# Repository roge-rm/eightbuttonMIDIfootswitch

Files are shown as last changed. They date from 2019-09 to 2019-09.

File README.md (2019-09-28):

# eightbuttonMIDIfootswitch
An eight button USB/5 pin MIDI footswitch. 

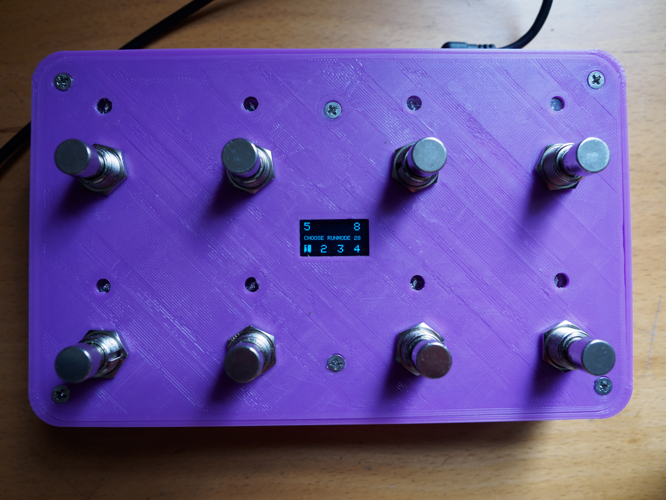
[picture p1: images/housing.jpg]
<br>
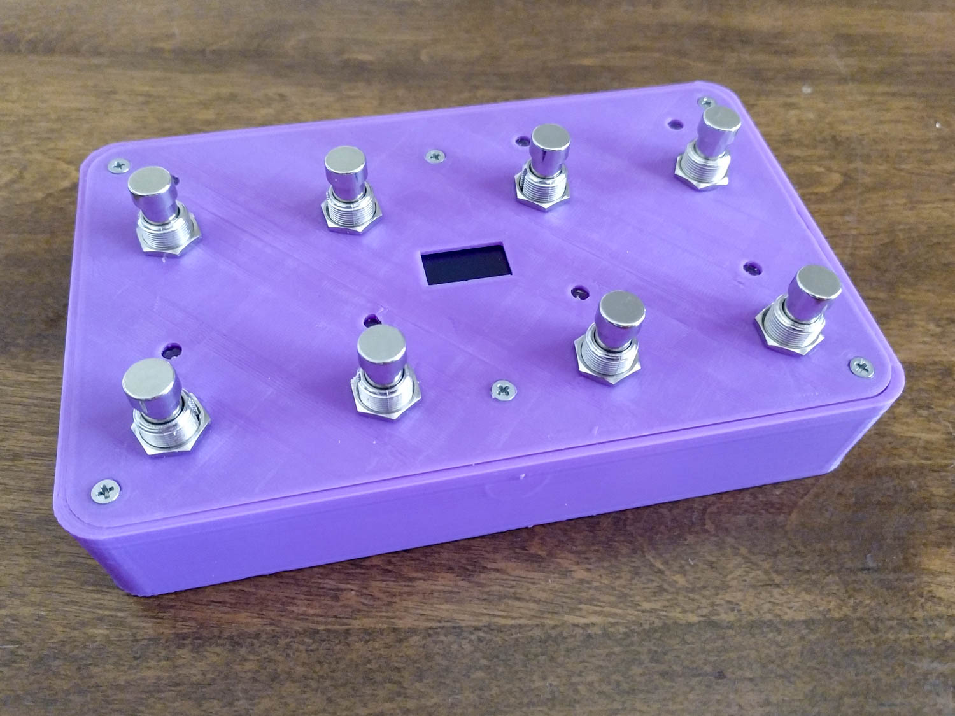
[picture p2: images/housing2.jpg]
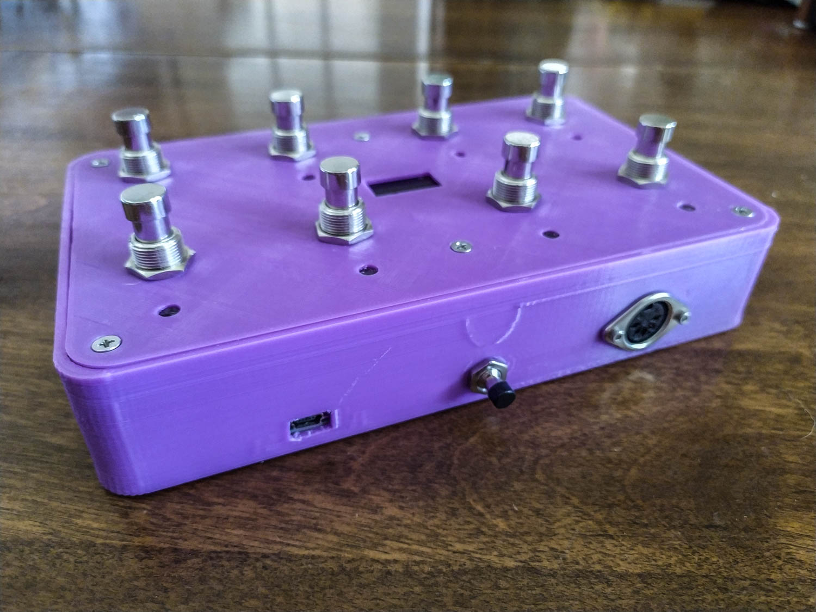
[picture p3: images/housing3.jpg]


Check it out on Thingiverse here: https://www.thingiverse.com/thing:3840065  
I've uploaded a video briefly showing how this works: https://www.youtube.com/watch?v=9XS2CDV4Rg0

I built this to go along with my [Synthstrom Deluge](https://synthstrom.com/product/deluge/) as a way to manage the new looping functionality in the (now out) 3.0 firmware. I wanted to be able to turn the loop mode on/off, as well as other various functions, either via USB MIDI or via standard 5-pin MIDI. This does that, and more! 

You can use either [toggle (latching)](https://github.com/hunked/eightbuttonMIDIfootswitch/blob/master/8buttonfootswitch-toggle.ino) or [momentary](https://github.com/hunked/eightbuttonMIDIfootswitch/blob/master/8buttonfootswitch-momentary.ino) switches. There are two versions of the code depending on which switch you use.

Currently there are 6 modes of operation selectable at boot. 
The selection screen can be returned to at any time by resetting the unit or pressing buttons 4 + 8 (top and bottom on the right side) together simultaneously.
- MIDI Note Momentary/Timed (on note sent on button press, off note sent after button is released (or preset time if using toggle switches))
- MIDI Note Toggle (press button once to turn on, press again to turn off)
- MIDI CC Momentary/Timed (same as mode 1 but with CC messages) 
- MIDI CC Toggle (same as mode 2 but with CC)
- Program Change (pressing each of the 8 buttons sends a different Program Change message)
- Settings Menu (change channels, MIDI messages, default options)

If you do not choose an option the footswitch will start the default (mode 1) after a set timeout (6 seconds). 

You can customize all of the messages sent by the footswitch. Currently the following options are configurable from the settings menu:
- CHAN - channel for NOTE/CC/PC messages (set separately)
- NOTE - MIDI note numbers and velocities
- CC - Control Change numbers and on/off values
- PC - Program Change numbers
- DEF - default runmode (RUNM), menu timeout (MENU), how long before OFF note/CC is sent (NOFF/COFF) (only in toggle version)
- LOAD - load values from EEPROM
- SAVE - save values to EEPROM (changes you make to settings will not be stored unless you press this)

The menu should be straight forward to use. There are a couple of screens that have no back button (due to all eight buttons being used for something else), they will time out to the previous screen after a set limit (which can be edited in the DEFaults menu).

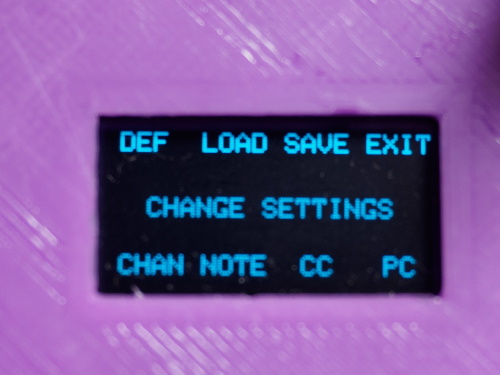
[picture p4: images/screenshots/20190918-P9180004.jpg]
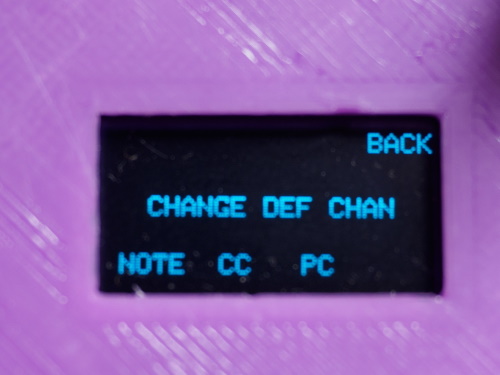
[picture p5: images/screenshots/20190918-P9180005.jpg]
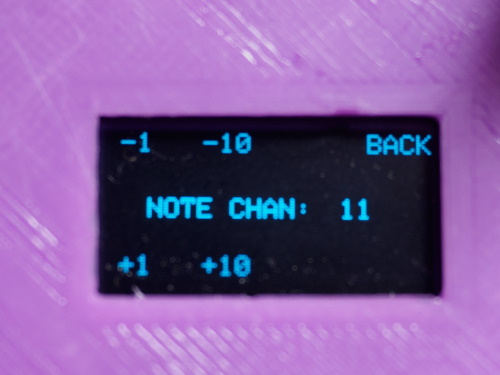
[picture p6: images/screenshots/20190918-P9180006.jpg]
<br>
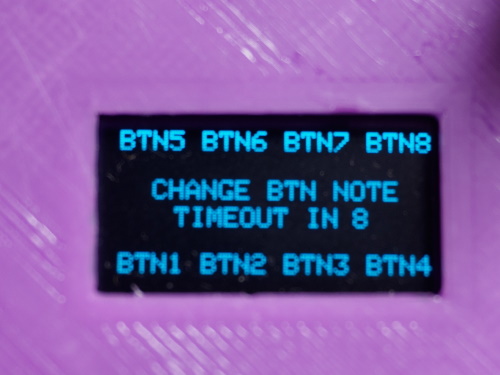
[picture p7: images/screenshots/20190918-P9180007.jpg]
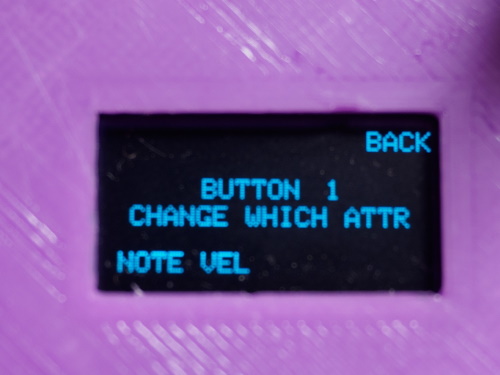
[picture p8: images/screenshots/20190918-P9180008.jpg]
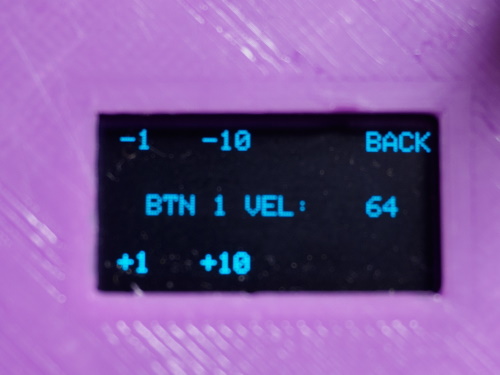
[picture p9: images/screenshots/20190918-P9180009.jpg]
<br>
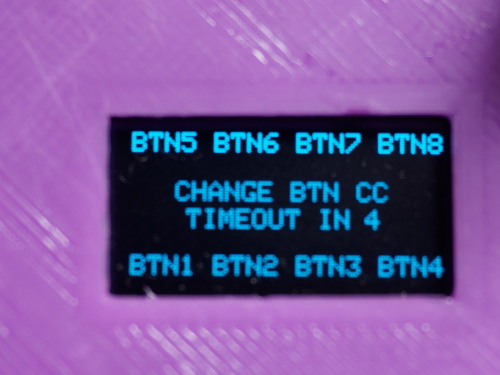
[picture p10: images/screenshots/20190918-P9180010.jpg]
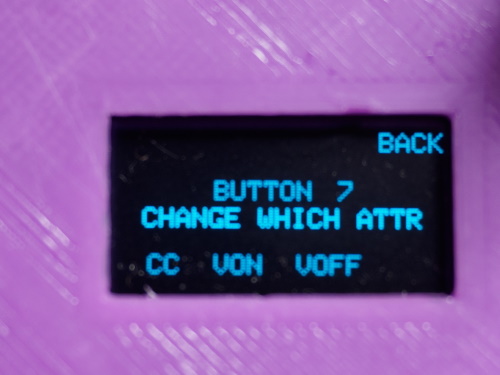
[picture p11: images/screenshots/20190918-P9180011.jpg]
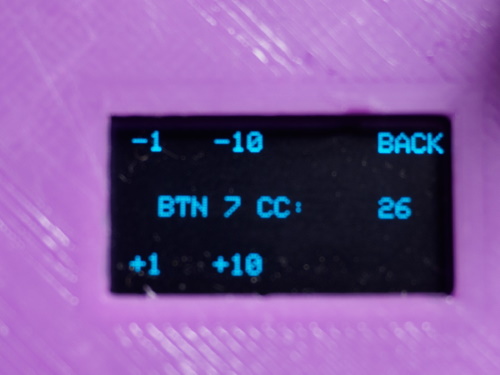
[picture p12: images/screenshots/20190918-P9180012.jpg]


#### Items used in this build:
- 3D Printer
- Soldering iron + solder
- Hookup wire (I used 28AWG) + appropriate heatshrink
- Tape (for binding wires, holding the OLED screen in place)
- Screwdriver
- Teensy ++2.0 (https://www.pjrc.com/store/teensypp.html)
- 8 x Guitar Footswitch, either momentary (https://www.aliexpress.com/item/32800932179.html) or latching (https://www.aliexpress.com/item/32826054526.html)
- 0.96" OLED I2C display (https://www.aliexpress.com/item/32896971385.html)
- 8 x 5mm 5V LEDs (https://www.aliexpress.com/item/32240559912.html)
- 5 pin MIDI port (https://www.aliexpress.com/item/32972269819.html)
- 2 x 220 ohm resistors for the MIDI port (see https://www.pjrc.com/teensy/td_libs_MIDI.html for wiring info)
- 7mm momentary push button (https://www.aliexpress.com/item/32790920961.html) as an easy way to update the Teensy without opening the case. Eventually I will replace this with a DC input jack.
- 6 x M3 countersunk screws, anything between 5 and 10mm in length will probably work (this is to hold the top of the housing down)
- 2 x M2 or M2.5 bolts and nuts, around 10mm length (to hold the MIDI port in place)

#### Rough pinout/wiring diagram:
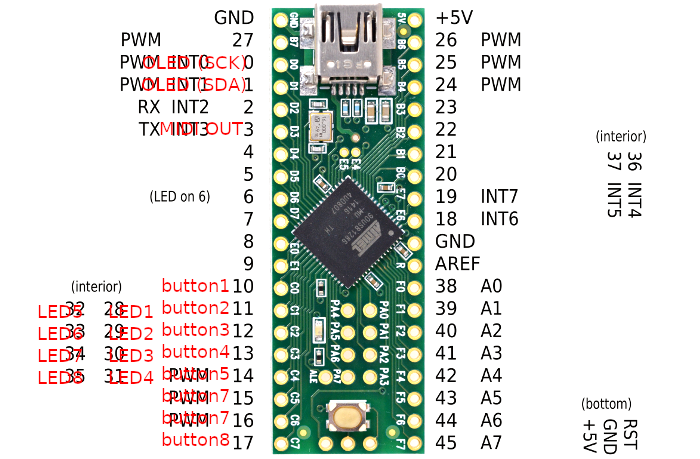
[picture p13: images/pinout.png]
Teensy ++2.0 Pinout


I have exported a schematic from KiCad that goes into more detail:
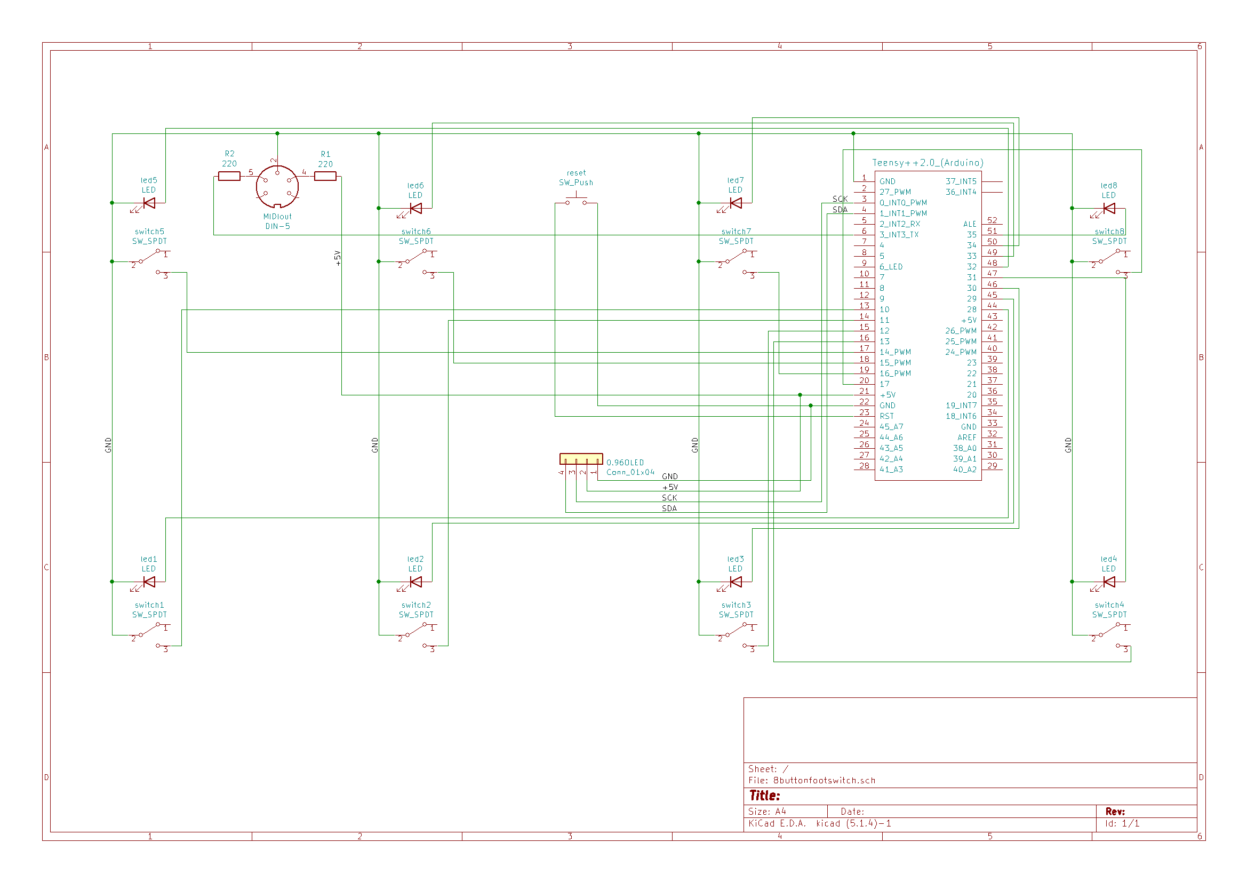
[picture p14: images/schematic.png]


#### Assembly instructions:
You can check out some pictures of my wiring [here](https://raw.githubusercontent.com/hunked/eightbuttonMIDIfootswitch/master/images/wiring1.jpg), [here](https://raw.githubusercontent.com/hunked/eightbuttonMIDIfootswitch/master/images/wiring2.jpg), and [here](https://raw.githubusercontent.com/hunked/eightbuttonMIDIfootswitch/master/images/wiring3.jpg).

- Print the top and bottom of the housing with your handy 3D printer (I use a Tevo Tarantula myself). I printed in PLA with a layer height of 0.3mm. You will need to use supports for the bottom of the housing.
- Install the OLED screen in the top housing. I initially planned to screw it into place but ended up using double sided tape for now. Screws would be a better idea but I haven't gone digging in my parts bin for something small enough yet.
- Wire the OLED screen to the Teensy, 5V and GND from wherever works for you and pin 0 for SCK/pin 1 for SDA.
- Install the footswitches in the top housing. Marvel at how footswitches are really hard to press with your fingers.
- Wire the footswitches to the Teensy. I wired the grounds first by daisy-chaining each switch to the next (and then the last switch the GND on the Teensy) and then wired the other sides of the switches to pins 10 through 17.
- Install the LEDs in the top housing. I made the holes in the top plate just large enough to jam the LEDs in so they don't need any glue. Maybe a little glue around the base wouldn't hurt.
- Wire the LEDs to the Teensy. I used pins 28 through 35 for the positive sides and then grounded each LED to the nearest switch. This is probably bad practice in electrical design but gosh darn if it doesn't make for some easier wiring.
- Install the 7mm momentary switch in the appropriate hole in the bottom of the case (you figure it out). This is handy for updating the firmware on the Teensy and I may use it as a way to change between footswitch functions in the future.
- Wire the 7mm momentary switch to the RST and GND pins on the end of the Teensy furthest from the USB port (the bottom, in the pinout diagram). 
- Solder 220 ohm resistors to pins 5 and 4 on the DIN-5 MIDI plug and install it into the bottom of the housing. See the MIDI library page [here](https://www.pjrc.com/teensy/td_libs_MIDI.html) for more information/diagrams.
- Wire the MIDI plug as shown in the [schematic](https://raw.githubusercontent.com/hunked/eightbuttonMIDIfootswitch/master/images/schematic.png). Pin 2 goes to GND (I ran it to the reset switch as it was close by), pin 5 (via 220 ohm resistor) goes to pin 3 on the Teensy, and pin 4 on the DIN-5 MIDI plug (via 220 ohm resistor) goes to a 5V pin on the Teensy (I used the one by the RST pin).
- Flash the appropriate code based on whether you used [momentary](https://github.com/hunked/eightbuttonMIDIfootswitch/blob/master/8buttonfootswitch-momentary.ino) or [toggle/latching](https://github.com/hunked/eightbuttonMIDIfootswitch/blob/master/8buttonfootswitch-toggle.ino) switches. If you used different pins than I did you will need to change the assignments in the code accordingly. **Make sure you set the USB Type (under Tools->USB Type) to MIDI.**
- Test it out! The LEDs will flash as you push the buttons and the screen will display the MIDI message number being sent. 
- Squish the wires into place, close the housing and screw it together. You may need to bore out the screw holes a bit with a drill.
- Stomp those switches until your roommate/neighbour/family member complains about the noise.

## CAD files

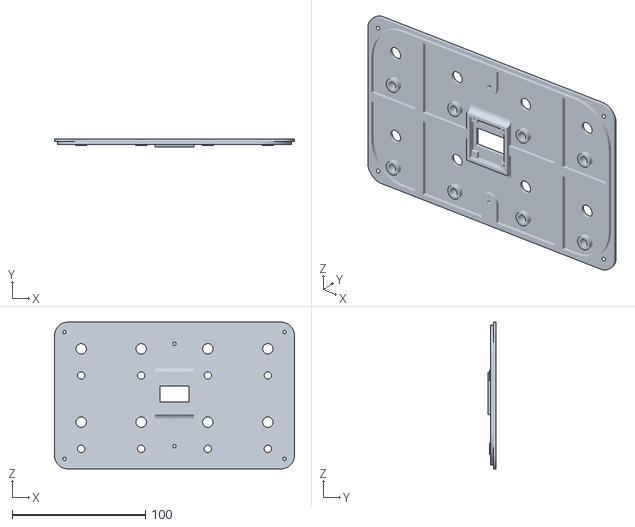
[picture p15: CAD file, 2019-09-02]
stl/8buttonMIDI-top-7mm.stl
180.0 x 6.00 x 110.0

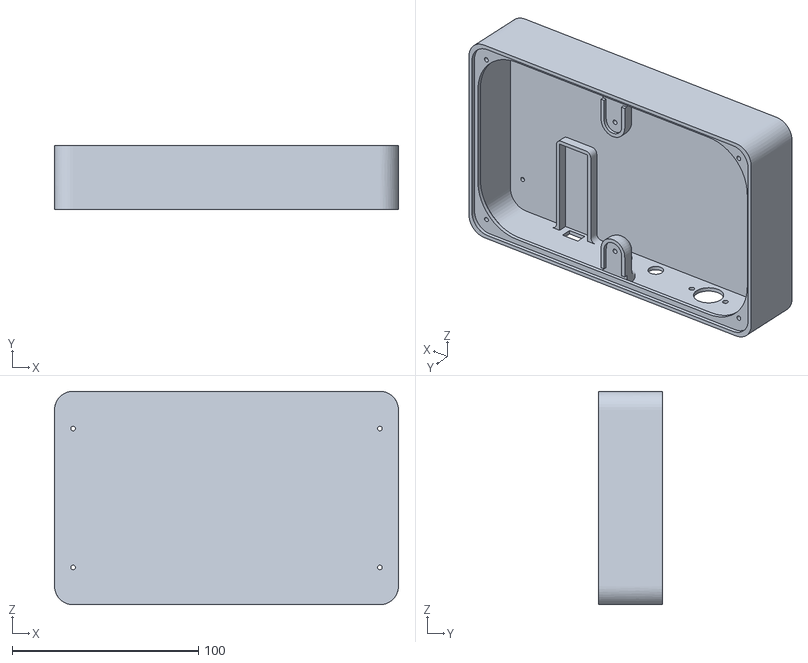
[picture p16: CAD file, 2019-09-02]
stl/8buttonMIDI-bottom-power&reset.stl
184.5 x 34.1 x 114.5

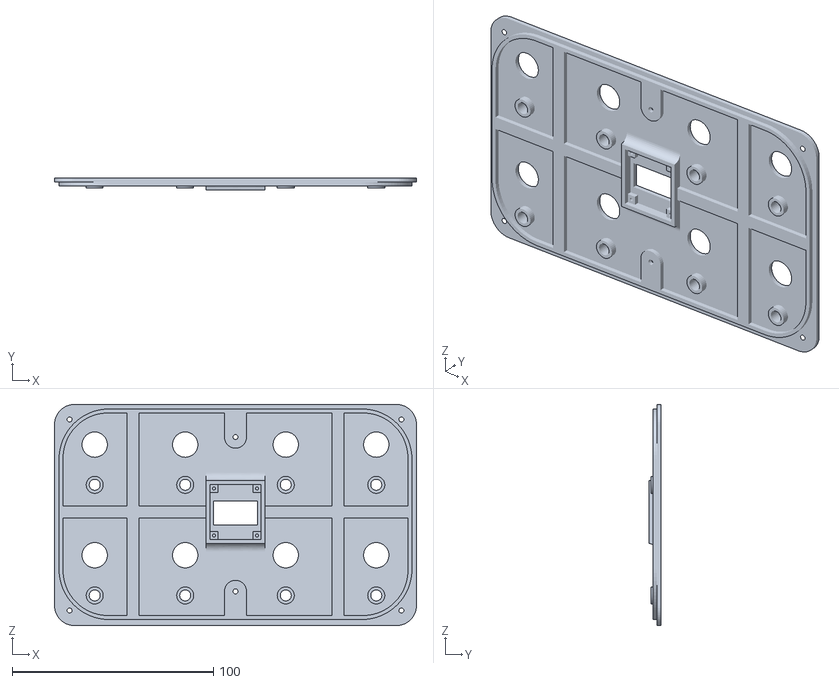
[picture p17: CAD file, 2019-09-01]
stl/8buttonMIDI-top.stl
180.0 x 6.00 x 110.0

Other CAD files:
stl/8buttonMIDI-bottom.stl

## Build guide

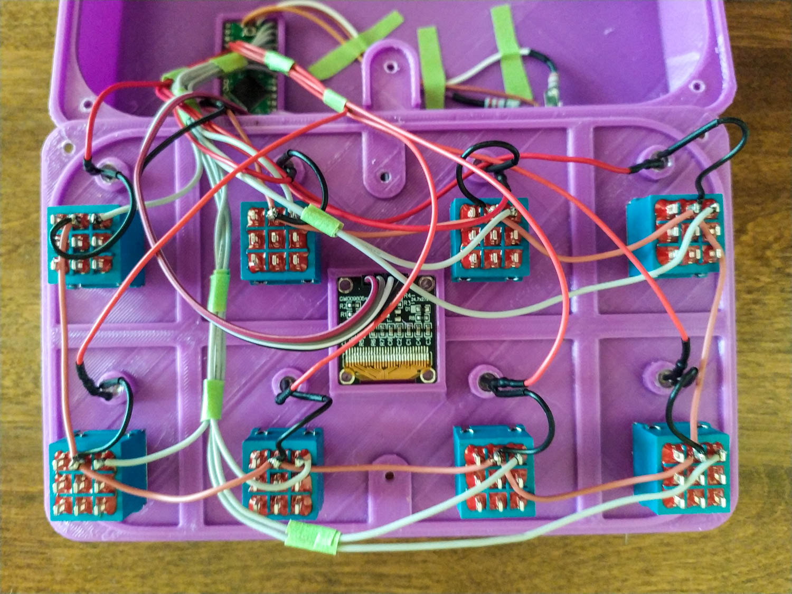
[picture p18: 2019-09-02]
images/wiring1.jpg

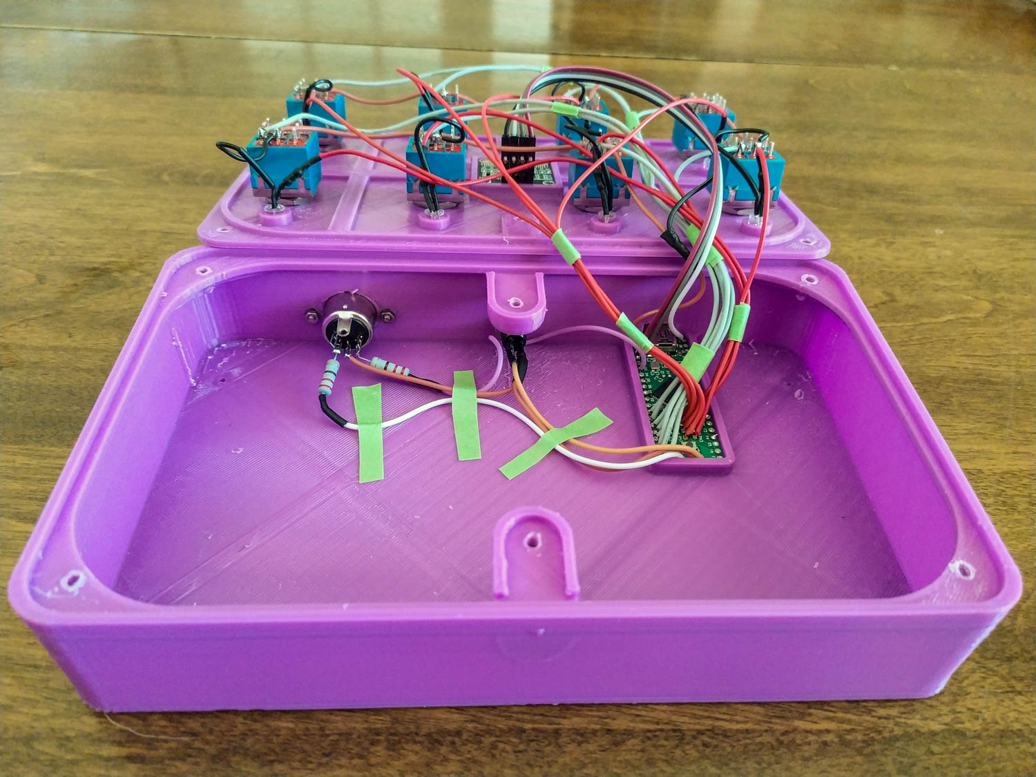
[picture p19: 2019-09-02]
images/wiring2.jpg

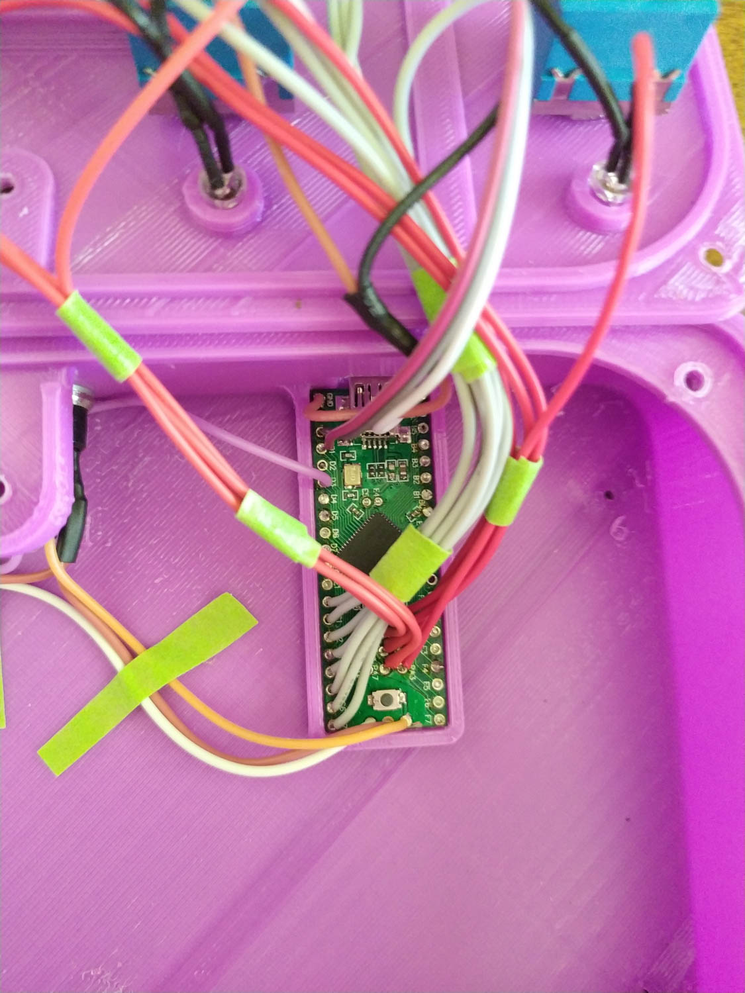
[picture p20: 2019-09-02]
images/wiring3.jpg

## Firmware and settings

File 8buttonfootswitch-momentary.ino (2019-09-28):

/*
 * This is for momentary switches. If you have toggle switches check out 8buttonfootswitch-toggle
 */

#include <SPI.h>
#include <Wire.h>
#include <Bounce.h>
#include <MIDI.h>
#include <EEPROM.h>
#include <Adafruit_GFX.h>
#include <Adafruit_SSD1306.h>

#define SCREEN_WIDTH 128 //OLED display width, in pixels
#define SCREEN_HEIGHT 64 //OLED display height, in pixels

//Declaration for an SSD1306 display connected to I2C (SDA, SCL pins)
#define OLED_RESET -1 //Reset pin # (or -1 if sharing Arduino reset pin)
Adafruit_SSD1306 display(SCREEN_WIDTH, SCREEN_HEIGHT, &Wire, OLED_RESET);

//Create MIDI instance for 5 pin MIDI output
MIDI_CREATE_INSTANCE(HardwareSerial, Serial1, MIDI);

//Declare pins for footswitches
const byte switchPin[8] = {10, 11, 12, 13, 14, 15, 16, 17};

//Declare pins for LEDs;
const byte ledPin[8] = {32, 33, 34, 35, 28, 29, 30, 31};
const int ledDelay = 500; //How long to light LEDs up for visual confirmation

//Default channel for MIDI notes, CC, program change, control change
int MIDI_NOTE_CHAN;
int MIDI_CC_CHAN;
int MIDI_PC_CHAN;

//Arrays are declared here but loaded from EEPROM/defaults in eepromREAD()
int switchNote[8];
int switchVel[8];
int switchCC[8];
int switchCCValOn[8];
int switchCCValOff[8];
int switchPC[8];

//Switch states for runmodes that require toggling
bool switchState[8] = {0, 0, 0, 0, 0, 0, 0, 0};

//Create Bounce objects for each button and switch.
//Default debounce time is 5ms
const int DEBOUNCE_TIME = 5;

Bounce button1 = Bounce(switchPin[0], DEBOUNCE_TIME);
Bounce button2 = Bounce(switchPin[1], DEBOUNCE_TIME);
Bounce button3 = Bounce(switchPin[2], DEBOUNCE_TIME);
Bounce button4 = Bounce(switchPin[3], DEBOUNCE_TIME);
Bounce button5 = Bounce(switchPin[4], DEBOUNCE_TIME);
Bounce button6 = Bounce(switchPin[5], DEBOUNCE_TIME);
Bounce button7 = Bounce(switchPin[6], DEBOUNCE_TIME);
Bounce button8 = Bounce(switchPin[7], DEBOUNCE_TIME);

//Track runmode (function of footswitch) as well as pick default option if no change is made before timeout. Default timeout is 6000ms.
//0 = Startup screen (runmode select)
//1 = MIDI Note ON+OFF (timed), 2 = MIDI Note Toggle (must hit switch again to turn off)
//3 = MIDI CC ON+OFF (timed), 4 = MIDI CC Toggle (same as MIDI Note, but with CC)
//5 = Program Change, 8 = Settings
int RUNMODE = 0;
int RUNMODE_DEFAULT; //set by EEPROM
unsigned int RUNMODE_TIMEOUT = 6000;
const int RUNMODE_LONGTIMEOUT = 31000;

//Counter setup for menus requiring timeouts (due to lack of a back button)
unsigned long previousMillis = 0;

//For settings menu navigation
int menuCat[3] = {0, 0, 0};
unsigned long MENU_TIMEOUT;
unsigned long currentMillis = 0;

void setup() {
  eepromREAD(); //Set variable values from EEPROM (or defaults if EEPROM has not been written)

  //Serial.begin(9600); //Debugging

  MIDI.begin();

  //Configure switch pins as for input mode with pullup resistors
  pinMode (switchPin[0], INPUT_PULLUP);
  pinMode (switchPin[1], INPUT_PULLUP);
  pinMode (switchPin[2], INPUT_PULLUP);
  pinMode (switchPin[3], INPUT_PULLUP);
  pinMode (switchPin[4], INPUT_PULLUP);
  pinMode (switchPin[5], INPUT_PULLUP);
  pinMode (switchPin[6], INPUT_PULLUP);
  pinMode (switchPin[7], INPUT_PULLUP);

  //Configure LED pins for output
  pinMode (ledPin[0], OUTPUT);
  pinMode (ledPin[1], OUTPUT);
  pinMode (ledPin[2], OUTPUT);
  pinMode (ledPin[3], OUTPUT);
  pinMode (ledPin[4], OUTPUT);
  pinMode (ledPin[5], OUTPUT);
  pinMode (ledPin[6], OUTPUT);
  pinMode (ledPin[7], OUTPUT);

  //SSD1306_SWITCHCAPVCC = generate display voltage from 3.3V internally
  if (!display.begin(SSD1306_SWITCHCAPVCC, 0x3C)) { //Address 0x3C for 128x64
    Serial.println(F("SSD1306 allocation failed"));
    for (;;); //Don't proceed, loop forever
  }

  updatebuttons(); //Pull initial button status to prevent phantom MIDI messages from being sent once the loop starts

  display.display();
  delay(500);

  display.clearDisplay();
}

void loop() {
  currentMillis = millis();
  display.clearDisplay();
  display.setTextSize(2);
  display.setTextColor(WHITE);

  updatebuttons(); //Poll for button presses

  if (RUNMODE == 0) {
    runmodeSELECTMODE();
  } else if (RUNMODE == 1) {
    runmodeMIDINOTETIMED();
  } else if (RUNMODE == 2) {
    runmodeMIDINOTETOGGLE();
  } else if (RUNMODE == 3) {
    runmodeCCTIMED();
  } else if (RUNMODE == 4) {
    runmodeCCTOGGLE();
  } else if (RUNMODE == 5) {
    runmodePROGRAMCHANGE();
  } else if (RUNMODE == 8) {
    runmodeSETTINGS();
  }

  //Break back to mode select. Set timeout to 31 seconds to give user more time for a selection
  if (button4.risingEdge() && button8.risingEdge()) {
    RUNMODE = 0;
    RUNMODE_TIMEOUT = RUNMODE_LONGTIMEOUT;
    resetSWITCHES();
    resetMENU();
    previousMillis = currentMillis;
  }

  while (usbMIDI.read()) //Ignore incoming MIDI
  {
  }
}

void updatebuttons() {
  button1.update();
  button2.update();
  button3.update();
  button4.update();
  button5.update();
  button6.update();
  button7.update();
  button8.update();
}

void runmodeSELECTMODE() { //Give choice between running modes, choose default mode after timeout if no option selected
  //unsigned long currentMillis = millis();
  long timeOut = (RUNMODE_TIMEOUT / 1000 - ((currentMillis - previousMillis) / 1000));

  display.setTextColor(WHITE, BLACK);
  display.setTextSize(1);
  display.setCursor(10, 34);
  display.println(F("CHOOSE RUNMODE"));
  display.setCursor(100, 34);
  display.println(timeOut);

  display.setTextSize(2);
  display.setCursor(10, 50);
  if (RUNMODE_DEFAULT == 1) {
    display.setTextColor(BLACK, WHITE);
  } else display.setTextColor(WHITE, BLACK);
  display.println(F("1"));
  display.setCursor(40, 50);
  if (RUNMODE_DEFAULT == 2) {
    display.setTextColor(BLACK, WHITE);
  } else display.setTextColor(WHITE, BLACK);
  display.println(F("2"));
  display.setCursor(70, 50);
  if (RUNMODE_DEFAULT == 3) {
    display.setTextColor(BLACK, WHITE);
  } else display.setTextColor(WHITE, BLACK);
  display.println(F("3"));
  display.setCursor(100, 50);
  if (RUNMODE_DEFAULT == 4) {
    display.setTextColor(BLACK, WHITE);
  } else display.setTextColor(WHITE, BLACK);
  display.println(F("4"));
  display.setCursor(10, 10);
  if (RUNMODE_DEFAULT == 5) {
    display.setTextColor(BLACK, WHITE);
  } else display.setTextColor(WHITE, BLACK);
  display.println(F("5"));
  display.setCursor(100, 10);
  display.setTextColor(WHITE, BLACK);
  display.println(F("8"));

  if (button1.fallingEdge()) {
    RUNMODE = 1;
    blinkLED(1);
    previousMillis = currentMillis;
  }
  if (button2.fallingEdge()) {
    RUNMODE = 2;
    blinkLED(2);
    previousMillis = currentMillis;
  }
  if (button3.fallingEdge()) {
    RUNMODE = 3;
    blinkLED(3);
    previousMillis = currentMillis;
  }
  if (button4.fallingEdge()) {
    RUNMODE = 4;
    blinkLED(4);
    previousMillis = currentMillis;
  }
  if (button5.fallingEdge()) {
    RUNMODE = 5;
    blinkLED(5);
    previousMillis = currentMillis;
  }
  if (button8.fallingEdge()) {
    RUNMODE = 8;
    blinkLED(8);
    previousMillis = currentMillis;
  }

  if (currentMillis - previousMillis >= RUNMODE_TIMEOUT) {
    RUNMODE = RUNMODE_DEFAULT;
    blinkLED(RUNMODE_DEFAULT);
    previousMillis = currentMillis;
  }

  display.setTextColor(WHITE, BLACK);
  display.display();
}


void runmodeMIDINOTETIMED() {
  if (button1.fallingEdge()) {
    display.setCursor(10, 50);
    display.println(switchNote[0]);
    digitalWrite(ledPin[0], HIGH);
    usbMIDI.sendNoteOn(switchNote[0], switchVel[0], MIDI_NOTE_CHAN);
    MIDI.sendNoteOn(switchNote[0], switchVel[0], MIDI_NOTE_CHAN);
  }
  else if (button1.risingEdge()) {
    display.setCursor(10, 50);
    display.println(switchNote[0]);
    usbMIDI.sendNoteOff(switchNote[0], 0, MIDI_NOTE_CHAN);
    MIDI.sendNoteOff(switchNote[0], 0, MIDI_NOTE_CHAN);
    digitalWrite(ledPin[0], LOW);
  }

  if (button2.fallingEdge()) {
    display.setCursor(40, 50);
    display.println(switchNote[1]);
    digitalWrite(ledPin[1], HIGH);
    usbMIDI.sendNoteOn(switchNote[1], switchVel[1], MIDI_NOTE_CHAN);
    MIDI.sendNoteOn(switchNote[1], switchVel[1], MIDI_NOTE_CHAN);
  }
  else if (button2.risingEdge()) {
    display.setCursor(40, 50);
    display.println(switchNote[1]);
    usbMIDI.sendNoteOff(switchNote[1], 0, MIDI_NOTE_CHAN);
    MIDI.sendNoteOff(switchNote[1], 0, MIDI_NOTE_CHAN);
    digitalWrite(ledPin[1], LOW);
  }

  if (button3.fallingEdge()) {
    display.setCursor(70, 50);
    display.println(switchNote[2]);
    digitalWrite(ledPin[2], HIGH);
    usbMIDI.sendNoteOn(switchNote[2], switchVel[2], MIDI_NOTE_CHAN);
    MIDI.sendNoteOn(switchNote[2], switchVel[2], MIDI_NOTE_CHAN);
  }
  else if (button3.risingEdge()) {
    display.setCursor(70, 50);
    display.println(switchNote[2]);
    usbMIDI.sendNoteOff(switchNote[2], 0, MIDI_NOTE_CHAN);
    MIDI.sendNoteOff(switchNote[2], 0, MIDI_NOTE_CHAN);
    digitalWrite(ledPin[2], LOW);
  }

  if (button4.fallingEdge()) {
    display.setCursor(100, 50);
    display.println(switchNote[3]);
    digitalWrite(ledPin[3], HIGH);
    usbMIDI.sendNoteOn(switchNote[3], switchVel[3], MIDI_NOTE_CHAN);
    MIDI.sendNoteOn(switchNote[3], switchVel[3], MIDI_NOTE_CHAN);
  }
  else if (button4.risingEdge()) {
    display.setCursor(100, 50);
    display.println(switchNote[3]);
    usbMIDI.sendNoteOff(switchNote[3], 0, MIDI_NOTE_CHAN);
    MIDI.sendNoteOff(switchNote[3], 0, MIDI_NOTE_CHAN);
    digitalWrite(ledPin[3], LOW);
  }

  if (button5.fallingEdge()) {
    display.setCursor(10, 10);
    display.println(switchNote[4]);
    digitalWrite(ledPin[4], HIGH);
    usbMIDI.sendNoteOn(switchNote[4], switchVel[4], MIDI_NOTE_CHAN);
    MIDI.sendNoteOn(switchNote[4], switchVel[4], MIDI_NOTE_CHAN);
  }
  else if (button5.risingEdge()) {
    display.setCursor(10, 10);
    display.println(switchNote[4]);
    usbMIDI.sendNoteOff(switchNote[4], 0, MIDI_NOTE_CHAN);
    MIDI.sendNoteOff(switchNote[4], 0, MIDI_NOTE_CHAN);
    digitalWrite(ledPin[4], LOW);
  }

  if (button6.fallingEdge()) {
    display.setCursor(40, 10);
    display.println(switchNote[5]);
    digitalWrite(ledPin[5], HIGH);
    usbMIDI.sendNoteOn(switchNote[5], switchVel[5], MIDI_NOTE_CHAN);
    MIDI.sendNoteOn(switchNote[5], switchVel[5], MIDI_NOTE_CHAN);
  }
  else if (button6.risingEdge()) {
    display.setCursor(40, 10);
    display.println(switchNote[5]);
    usbMIDI.sendNoteOff(switchNote[5], 0, MIDI_NOTE_CHAN);
    MIDI.sendNoteOff(switchNote[5], 0, MIDI_NOTE_CHAN);
    digitalWrite(ledPin[5], LOW);
  }

  if (button7.fallingEdge()) {
    display.setCursor(70, 10);
    display.println(switchNote[6]);
    digitalWrite(ledPin[6], HIGH);
    usbMIDI.sendNoteOn(switchNote[6], switchVel[6], MIDI_NOTE_CHAN);
    MIDI.sendNoteOn(switchNote[6], switchVel[6], MIDI_NOTE_CHAN);
  }
  else if (button7.risingEdge()) {
    display.setCursor(70, 10);
    display.println(switchNote[6]);
    usbMIDI.sendNoteOff(switchNote[6], 0, MIDI_NOTE_CHAN);
    MIDI.sendNoteOff(switchNote[6], 0, MIDI_NOTE_CHAN);
    digitalWrite(ledPin[6], LOW);
  }

  if (button8.fallingEdge()) {
    display.setCursor(100, 10);
    display.println(switchNote[7]);
    digitalWrite(ledPin[7], HIGH);
    usbMIDI.sendNoteOn(switchNote[7], switchVel[7], MIDI_NOTE_CHAN);
    MIDI.sendNoteOn(switchNote[7], switchVel[7], MIDI_NOTE_CHAN);
  }
  else if (button8.risingEdge()) {
    display.setCursor(100, 10);
    display.println(switchNote[7]);
    usbMIDI.sendNoteOff(switchNote[7], 0, MIDI_NOTE_CHAN);
    MIDI.sendNoteOff(switchNote[7], 0, MIDI_NOTE_CHAN);
    digitalWrite(ledPin[7], LOW);
  }

  display.display();
}

void runmodeMIDINOTETOGGLE() {
  if (button1.fallingEdge()) {
    display.setCursor(10, 50);
    display.println(switchNote[0]);
    if (!switchState[0]) {
      digitalWrite(ledPin[0], HIGH);
      usbMIDI.sendNoteOn(switchNote[0], switchVel[0], MIDI_NOTE_CHAN);
      MIDI.sendNoteOn(switchNote[0], switchVel[0], MIDI_NOTE_CHAN);
      switchState[0] = 1;
    } else {
      usbMIDI.sendNoteOff(switchNote[0], 0, MIDI_NOTE_CHAN);
      MIDI.sendNoteOff(switchNote[0], 0, MIDI_NOTE_CHAN);
      digitalWrite(ledPin[0], LOW);
      switchState[0] = 0;
    }
  }

  if (button2.fallingEdge()) {
    display.setCursor(40, 50);
    display.println(switchNote[1]);
    if (!switchState[1]) {
      digitalWrite(ledPin[1], HIGH);
      usbMIDI.sendNoteOn(switchNote[1], switchVel[1], MIDI_NOTE_CHAN);
      MIDI.sendNoteOn(switchNote[1], switchVel[1], MIDI_NOTE_CHAN);
      switchState[1] = 1;
    } else {
      usbMIDI.sendNoteOff(switchNote[1], 0, MIDI_NOTE_CHAN);
      MIDI.sendNoteOff(switchNote[1], 0, MIDI_NOTE_CHAN);
      digitalWrite(ledPin[1], LOW);
      switchState[1] = 0;
    }
  }

  if (button3.fallingEdge()) {
    display.setCursor(70, 50);
    display.println(switchNote[2]);
    if (!switchState[2]) {
      digitalWrite(ledPin[2], HIGH);
      usbMIDI.sendNoteOn(switchNote[2], switchVel[2], MIDI_NOTE_CHAN);
      MIDI.sendNoteOn(switchNote[2], switchVel[2], MIDI_NOTE_CHAN);
      switchState[2] = 1;
    } else {
      usbMIDI.sendNoteOff(switchNote[2], 0, MIDI_NOTE_CHAN);
      MIDI.sendNoteOff(switchNote[2], 0, MIDI_NOTE_CHAN);
      digitalWrite(ledPin[2], LOW);
      switchState[2] = 0;
    }
  }

  if (button4.fallingEdge()) {
    display.setCursor(100, 50);
    display.println(switchNote[3]);
    if (!switchState[3]) {
      digitalWrite(ledPin[3], HIGH);
      usbMIDI.sendNoteOn(switchNote[3], switchVel[3], MIDI_NOTE_CHAN);
      MIDI.sendNoteOn(switchNote[3], switchVel[3], MIDI_NOTE_CHAN);
      switchState[3] = 1;
    } else {
      usbMIDI.sendNoteOff(switchNote[3], 0, MIDI_NOTE_CHAN);
      MIDI.sendNoteOff(switchNote[3], 0, MIDI_NOTE_CHAN);
      digitalWrite(ledPin[3], LOW);
      switchState[3] = 0;
    }
  }

  if (button5.fallingEdge()) {
    display.setCursor(10, 10);
    display.println(switchNote[4]);
    if (!switchState[4]) {
      digitalWrite(ledPin[4], HIGH);
      usbMIDI.sendNoteOn(switchNote[4], switchVel[4], MIDI_NOTE_CHAN);
      MIDI.sendNoteOn(switchNote[4], switchVel[4], MIDI_NOTE_CHAN);
      switchState[4] = 1;
    } else {
      usbMIDI.sendNoteOff(switchNote[4], 0, MIDI_NOTE_CHAN);
      MIDI.sendNoteOff(switchNote[4], 0, MIDI_NOTE_CHAN);
      digitalWrite(ledPin[4], LOW);
      switchState[4] = 0;
    }
  }

  if (button6.fallingEdge()) {
    display.setCursor(40, 10);
    display.println(switchNote[5]);
    if (!switchState[5]) {
      digitalWrite(ledPin[5], HIGH);
      usbMIDI.sendNoteOn(switchNote[5], switchVel[5], MIDI_NOTE_CHAN);
      MIDI.sendNoteOn(switchNote[5], switchVel[5], MIDI_NOTE_CHAN);
      switchState[5] = 1;
    } else {
      usbMIDI.sendNoteOff(switchNote[5], 0, MIDI_NOTE_CHAN);
      MIDI.sendNoteOff(switchNote[5], 0, MIDI_NOTE_CHAN);
      digitalWrite(ledPin[5], LOW);
      switchState[5] = 0;
    }
  }

  if (button7.fallingEdge()) {
    display.setCursor(70, 10);
    display.println(switchNote[6]);
    if (!switchState[6]) {
      digitalWrite(ledPin[6], HIGH);
      usbMIDI.sendNoteOn(switchNote[6], switchVel[6], MIDI_NOTE_CHAN);
      MIDI.sendNoteOn(switchNote[6], switchVel[6], MIDI_NOTE_CHAN);
      switchState[6] = 1;
    } else {
      usbMIDI.sendNoteOff(switchNote[6], 0, MIDI_NOTE_CHAN);
      MIDI.sendNoteOff(switchNote[6], 0, MIDI_NOTE_CHAN);
      digitalWrite(ledPin[6], LOW);
      switchState[6] = 0;
    }
  }

  if (button8.fallingEdge()) {
    display.setCursor(100, 10);
    display.println(switchNote[7]);
    if (!switchState[7]) {
      digitalWrite(ledPin[7], HIGH);
      usbMIDI.sendNoteOn(switchNote[7], switchVel[7], MIDI_NOTE_CHAN);
      MIDI.sendNoteOn(switchNote[7], switchVel[7], MIDI_NOTE_CHAN);
      switchState[7] = 1;
    } else {
      usbMIDI.sendNoteOff(switchNote[7], 0, MIDI_NOTE_CHAN);
      MIDI.sendNoteOff(switchNote[7], 0, MIDI_NOTE_CHAN);
      digitalWrite(ledPin[7], LOW);
      switchState[7] = 0;
    }
  }

  display.display();
}

void runmodeCCTIMED() {
  if (button1.fallingEdge()) {
    display.setCursor(10, 50);
    display.println(switchCC[0]);
    digitalWrite(ledPin[0], HIGH);
    usbMIDI.sendControlChange(switchCC[0], switchCCValOn[0], MIDI_CC_CHAN);
    MIDI.sendControlChange(switchCC[0], switchCCValOn[0], MIDI_CC_CHAN);
  }
  else if (button1.risingEdge()) {
    display.setCursor(10, 50);
    display.println(switchCC[0]);
    usbMIDI.sendControlChange(switchCC[0], switchCCValOff[0], MIDI_CC_CHAN);
    MIDI.sendControlChange(switchCC[0], switchCCValOff[0], MIDI_CC_CHAN);
    digitalWrite(ledPin[0], LOW);
  }

  if (button2.fallingEdge()) {
    display.setCursor(40, 50);
    display.println(switchCC[1]);
    digitalWrite(ledPin[1], HIGH);
    usbMIDI.sendControlChange(switchCC[1], switchCCValOn[1], MIDI_CC_CHAN);
    MIDI.sendControlChange(switchCC[1], switchCCValOn[1], MIDI_CC_CHAN);
  }
  else if (button2.risingEdge()) {
    display.setCursor(40, 50);
    display.println(switchCC[1]);
    usbMIDI.sendControlChange(switchCC[1], switchCCValOff[1], MIDI_CC_CHAN);
    MIDI.sendControlChange(switchCC[1], switchCCValOff[1], MIDI_CC_CHAN);
    digitalWrite(ledPin[1], LOW);
  }

  if (button3.fallingEdge()) {
    display.setCursor(70, 50);
    display.println(switchCC[2]);
    digitalWrite(ledPin[2], HIGH);
    usbMIDI.sendControlChange(switchCC[2], switchCCValOn[2], MIDI_CC_CHAN);
    MIDI.sendControlChange(switchCC[2], switchCCValOn[2], MIDI_CC_CHAN);
  }
  else if (button3.risingEdge()) {
    display.setCursor(70, 50);
    display.println(switchCC[2]);
    usbMIDI.sendControlChange(switchCC[2], switchCCValOff[2], MIDI_CC_CHAN);
    MIDI.sendControlChange(switchCC[2], switchCCValOff[2], MIDI_CC_CHAN);
    digitalWrite(ledPin[2], LOW);
  }

  if (button4.fallingEdge()) {
    display.setCursor(100, 50);
    display.println(switchCC[3]);
    digitalWrite(ledPin[3], HIGH);
    usbMIDI.sendControlChange(switchCC[3], switchCCValOn[3], MIDI_CC_CHAN);
    MIDI.sendControlChange(switchCC[3], switchCCValOn[3], MIDI_CC_CHAN);
  }
  else if (button4.risingEdge()) {
    display.setCursor(100, 50);
    display.println(switchCC[3]);
    usbMIDI.sendControlChange(switchCC[3], switchCCValOff[3], MIDI_CC_CHAN);
    MIDI.sendControlChange(switchCC[3], switchCCValOff[3], MIDI_CC_CHAN);
    digitalWrite(ledPin[3], LOW);
  }

  if (button5.fallingEdge()) {
    display.setCursor(10, 10);
    display.println(switchCC[4]);
    digitalWrite(ledPin[4], HIGH);
    usbMIDI.sendControlChange(switchCC[4], switchCCValOn[4], MIDI_CC_CHAN);
    MIDI.sendControlChange(switchCC[4], switchCCValOn[4], MIDI_CC_CHAN);
  }
  else if (button5.risingEdge()) {
    display.setCursor(10, 10);
    display.println(switchCC[4]);
    usbMIDI.sendControlChange(switchCC[4], switchCCValOff[4], MIDI_CC_CHAN);
    MIDI.sendControlChange(switchCC[4], switchCCValOff[4], MIDI_CC_CHAN);
    digitalWrite(ledPin[4], LOW);
  }

  if (button6.fallingEdge()) {
    display.setCursor(40, 10);
    display.println(switchCC[5]);
    digitalWrite(ledPin[5], HIGH);
    usbMIDI.sendControlChange(switchCC[5], switchCCValOn[5], MIDI_CC_CHAN);
    MIDI.sendControlChange(switchCC[5], switchCCValOn[5], MIDI_CC_CHAN);
  }
  else if (button6.risingEdge()) {
    display.setCursor(40, 10);
    display.println(switchCC[5]);
    usbMIDI.sendControlChange(switchCC[5], switchCCValOff[5], MIDI_CC_CHAN);
    MIDI.sendControlChange(switchCC[5], switchCCValOff[5], MIDI_CC_CHAN);
    digitalWrite(ledPin[5], LOW);
  }

  if (button7.fallingEdge()) {
    display.setCursor(70, 10);
    display.println(switchCC[6]);
    digitalWrite(ledPin[6], HIGH);
    usbMIDI.sendControlChange(switchCC[6], switchCCValOn[6], MIDI_CC_CHAN);
    MIDI.sendControlChange(switchCC[6], switchCCValOn[6], MIDI_CC_CHAN);
  }
  else if (button7.risingEdge()) {
    display.setCursor(70, 10);
    display.println(switchCC[6]);
    usbMIDI.sendControlChange(switchCC[6], switchCCValOff[6], MIDI_CC_CHAN);
    MIDI.sendControlChange(switchCC[6], switchCCValOff[6], MIDI_CC_CHAN);
    digitalWrite(ledPin[6], LOW);
  }

  if (button8.fallingEdge()) {
    display.setCursor(100, 10);
    display.println(switchCC[7]);
    digitalWrite(ledPin[7], HIGH);
    usbMIDI.sendControlChange(switchCC[7], switchCCValOn[7], MIDI_CC_CHAN);
    MIDI.sendControlChange(switchCC[7], switchCCValOn[7], MIDI_CC_CHAN);
  }
  else if (button8.risingEdge()) {
    display.setCursor(100, 10);
    display.println(switchCC[7]);
    usbMIDI.sendControlChange(switchCC[7], switchCCValOff[7], MIDI_CC_CHAN);
    MIDI.sendControlChange(switchCC[7], switchCCValOff[7], MIDI_CC_CHAN);
    digitalWrite(ledPin[7], LOW);
  }

  display.display();
}
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

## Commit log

2019-09-01 rough schematic done in KiCad
2019-09-01 updated MIDI PIN labels
2019-09-02 added a lot of functionality
    The code has changed quite a bit as I've added complication and moved values into arrays (easier to reference later). I'm learning as I go along, how fun!
    Added a bunch of new functionality, a little menu at startup and 5 different modes of operation (in total). The modes are:
    1 = MIDI Note ON+OFF (timed)
    2 = MIDI Note Toggle (must hit switch again to turn off)
    3 = MIDI CC ON+OFF (timed)
    4 = MIDI CC Toggle (same as MIDI Note, but with CC)
    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
2019-09-02 updated STLs
    [8buttonMIDI-bottom-power&reset.stl, 8buttonMIDI-bottom.stl, 8buttonMIDI-top-7mm.stl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]
2019-09-18 SETTINGS/SAVING/LOADING
    Added a settings menu (button 8 at the runmode select). MIDI notes/velocities, CC/PC, default runmode and timeouts can all be changed from the menu and will be loaded automatically (once saved).
    Runmode selection screen can now be returned to at any time by pressing butttons 4+8 together (good luck).
    Now saves to EEPROM when you press the save button in the settings menu. Loads from EEPROM every start if values have been changed.
2019-09-19 Add files via upload
    bracket placement is important!
2019-09-20 Add files via upload
    wrong LED number
2019-09-28 two versions of code for latching/momentary switches
2019-09-28 Momentary/toggle switch choice update
    You can now use momentary or toggle switches based on your preference.
    There are two versions of the code, named 8buttonfootswitch-toggle.ino and 8buttonfootswitch-momentary.ino.
